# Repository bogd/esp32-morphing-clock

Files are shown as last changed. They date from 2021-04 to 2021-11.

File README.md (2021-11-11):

# esp32-morphing-clock
ESP32 HUB75 Matrix Morphing Clock

A clock based on a HUB75 RGB LED matrix, controlled by an ESP32.



So far, it does the following:
* Displays the current date, time, and day of the week
* Updates the time on startup and periodically, via NTP
* Displays the current outdoor temperature and humidity (received via MQTT - if you want to use this, you will need an MQTT server and a separate temperature sensor publishing to it!)
* Displays the current light levels, read via a TSL2591 I2C light sensor
* Displays the weather forecast for current day (including min/max temperatures), and for the next 4 days
* Can receive OTA updates, triggered via an MQTT message (of course, this also requires an MQTT server :) )

This is very much a work in progress, and it is far from being finished. Things that are planned for the future include:
* Use the current light levels to control the matrix brightness
* Display alerts on-screen (received via MQTT)
* Use the buzzer module to get the user's attention when an alert comes in

You can find the "components" for the project here:
* The full source code is [here](code/)  - requires PlatformIO!
* The schematics for the PCB used is [here](pcb/)
* The drawings for the lasercut plexiglass enclosure are [here](case/)

## Changelog

### Version 0.2
* Added MQTT SSL support (thanks to [Andreas](https://github.com/lefty01)). Disabled by default, since I do not use it when testing
* Implemented weather forecast - clock now displays min/max temperature for today, today's + next 4 days' forecast icons
* Decreased light sensor read interval (interval is now configurable from config.h)
* Added a watchdog timer to automatically reset the unit (sometimes the main thread seems to hang, possibly due to the light sensor read?)

## Thanks

This project would not have been possible without the work of many others, who have been gracious enough to open source their work. Some of the things that I have used when building this:
* The MQTT SSL code contributed by [Andreas](https://github.com/lefty01)
* The PxMatrix library from [2dom](https://github.com/2dom/PxMatrix). Even though this is NOT used in this project (I switched to the DMA library below, for performance reasons), it is the library that got me started on working with HUB75 matrices.
* The ESP32 DMA library for controlling the matrix, from [mrfaptastic](https://github.com/mrfaptastic/ESP32-HUB75-MatrixPanel-I2S-DMA)
* The morphing clock code from [HariFun](https://www.instructables.com/Morphing-Digital-Clock/) (modified to work with mrfaptastic's library instead of pxmatrix)
* The shield schematics from [hallard](https://github.com/hallard/WeMos-Matrix-Shield-DMA), which gave me the confidence to try building my own version of a shield PCB :)

And, of course, all the authors of the various open source libraries (there are already too many to mention :) ).

I also have to mention here [Brian Lough's work](https://www.tindie.com/products/brianlough/esp32-i2s-matrix-shield/) on a shield for the matrix. Even though he decided not to open source the board (he only sells the finished board on tindie), he has been extremely helpful during my initial work on the project. So if you are looking for a simple option for getting the full kit (shield and components, all in one package), take a look at [his tindie page](https://www.tindie.com/products/brianlough/esp32-matrix-shield-mini-32/) .

## License

The ESP32 HUB75 Matrix Morphing Clock is (c) [Bogdan Sass](https://github.com/bogd), licensed with GNU General Public License Version 3.0 (which means, if you use it in a product somewhere, you need to make the source and all your modifications available to the receiver of such product so that they have the freedom to adapt and improve).

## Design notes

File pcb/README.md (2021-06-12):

# ESP32 Morphing Clock Shield PCB

## Info

Features:
* 16-wire ribbon cable connection to the RGB matrix
* Mounting holes for securing the shield to the enclosure
* Options for both PTH and SMD (0805/SOD-323) parts for all parts
* Multiple JST-XH (2.54mm) connectors for I2C sensors and for GPIOs (use for push-buttons, for example)
* Exposed JTAG and PROG connectors, for use with debugging/programming via ESP32-Prog (although they are a bit too close together in v0.3 :) )

**WARNING!!** Do not use v0.1 of the boards! I have made several mistakes while designing them (reversed OE/LAT pins on the matrix connector, and put in a WAY too thin power supply trace). As a result, I was unable to get the ESP32 to even boot when connected to these boards.

v0.3 has been tested, and works reliably.

## Components

These are the components that you will need to populate the PCB:
* R1, R2 (I2C pull-up resistors) - 4k7 ohm, PTH or 0805 SMD
* C1,C2,C3 (decoupling capacitor(s)) - either 100uF PTH, or 2x47uF SMD
* D1 (protection diode, prevents the matrix from pulling too much power from your USB port) - any Schottky will work. For example: BAT85 (PTH), or 1N5819 (SOD-323)
* P1 - ribbon cable connector, 2x8 pin
* GND_T/5V_T - 2xScrew terminal blocks, 5.0mm
* power connection - 2.1/5.5mm PCB connector, or **7.62mm** screw terminal block
* I2C and GPIO connectors - JST-XH 2.54mm, 2 and 4-pin 

And, of course, you will need the ESP32 board - it has to be the D1 Mini version:
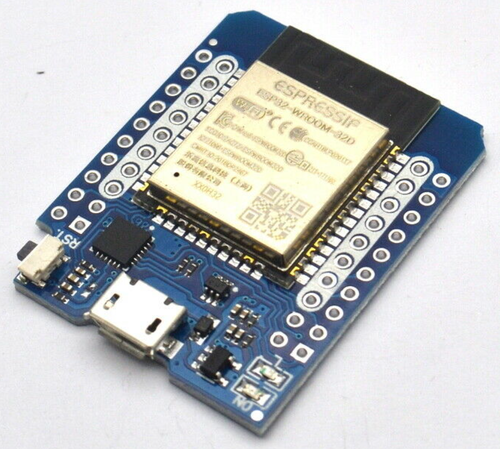
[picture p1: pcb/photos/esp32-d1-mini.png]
ESP32 D1 Mini


## Board 

Images of the completed board:
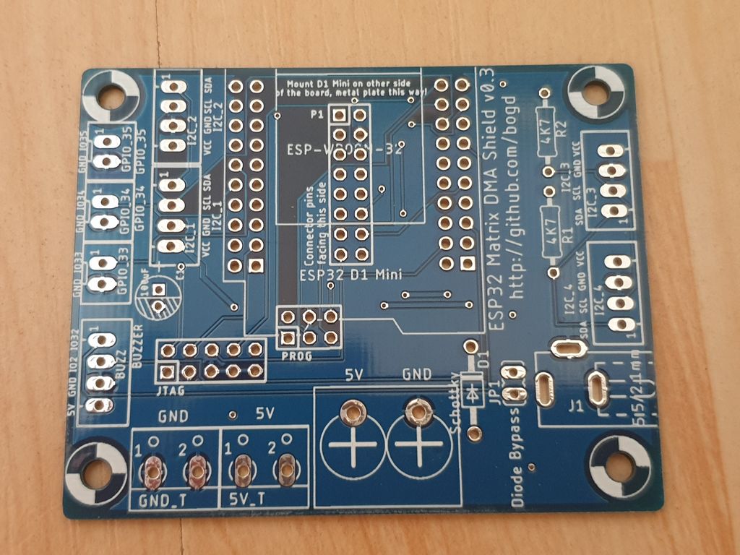
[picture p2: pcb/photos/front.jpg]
Front

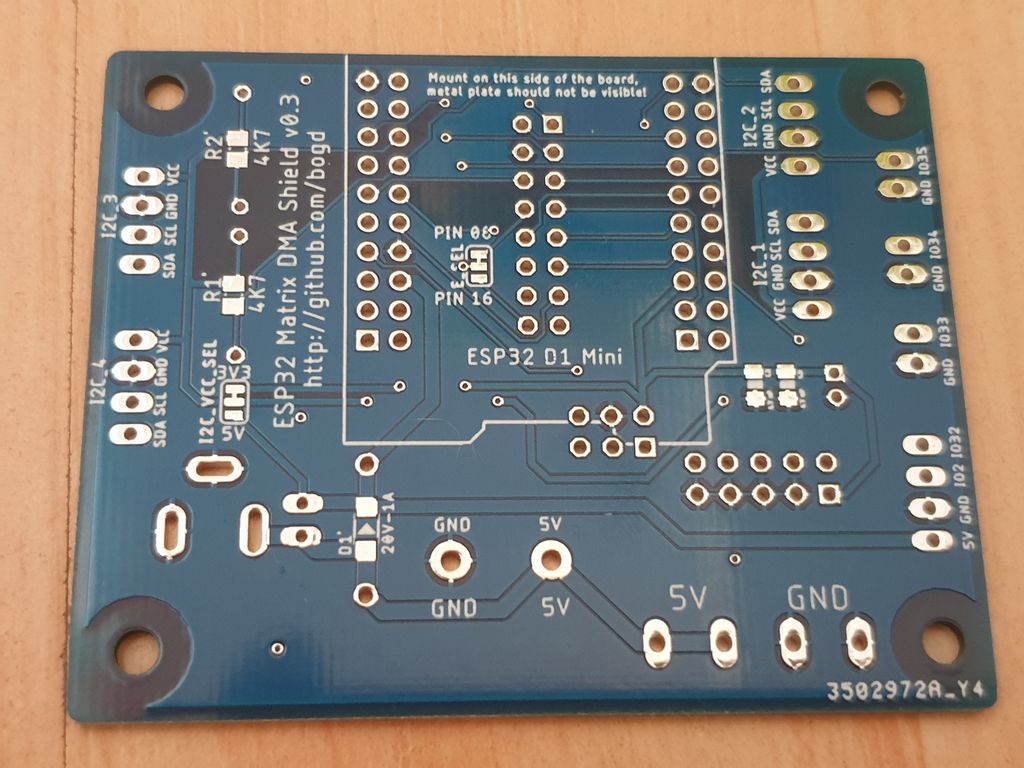
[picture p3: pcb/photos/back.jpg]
Back


The board with (a minimum of) components soldered on:
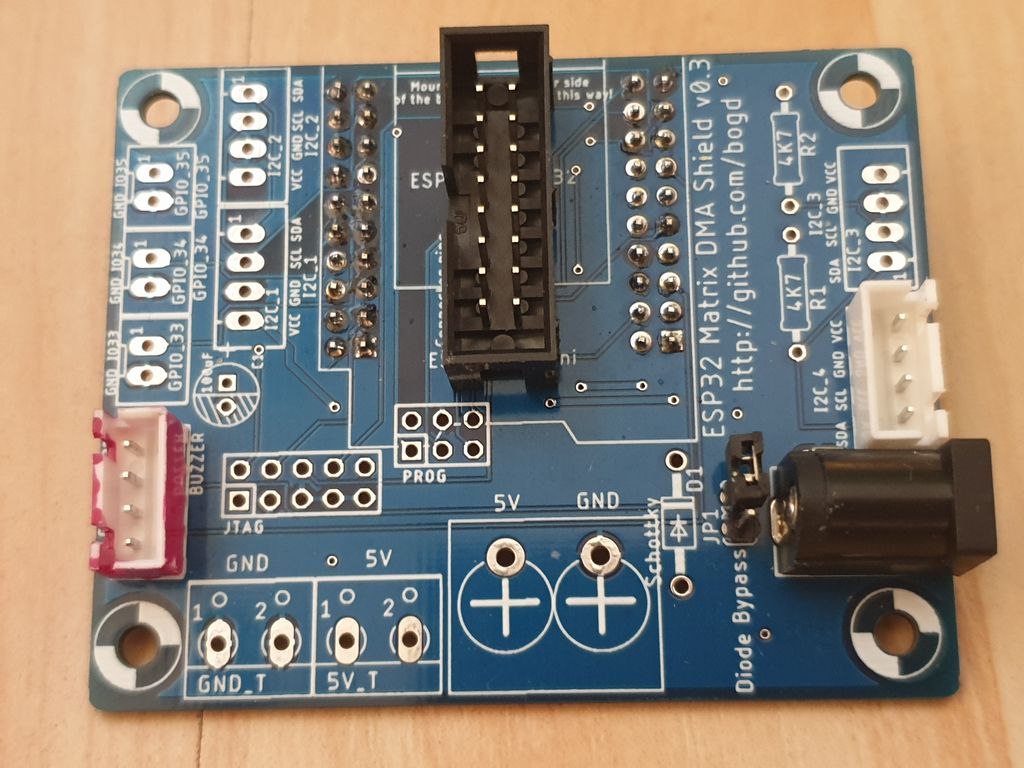
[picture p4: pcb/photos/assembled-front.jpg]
Assembled Front

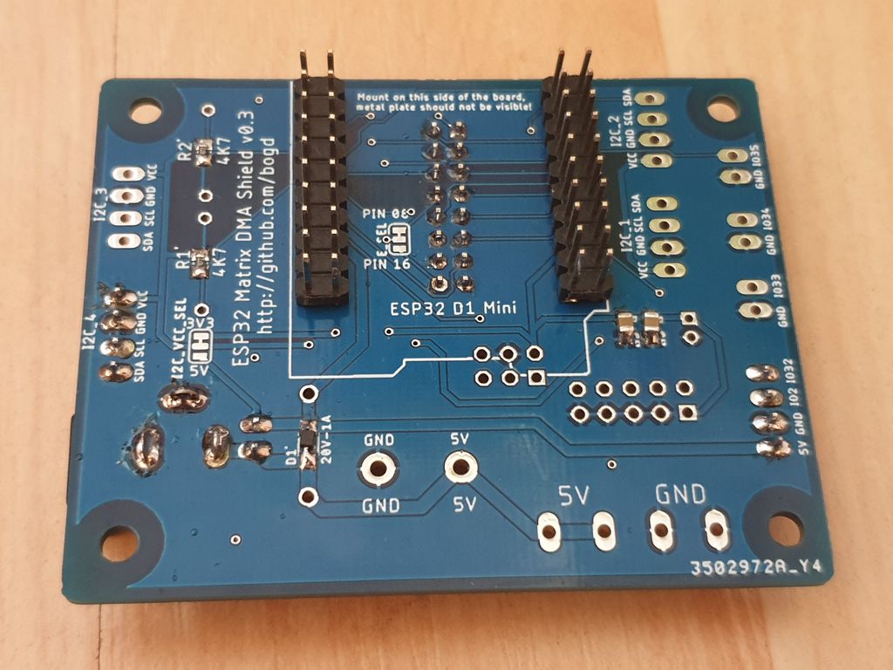
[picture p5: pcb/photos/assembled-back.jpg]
Assembled Back


Connected to the matrix and the ESP32 module:
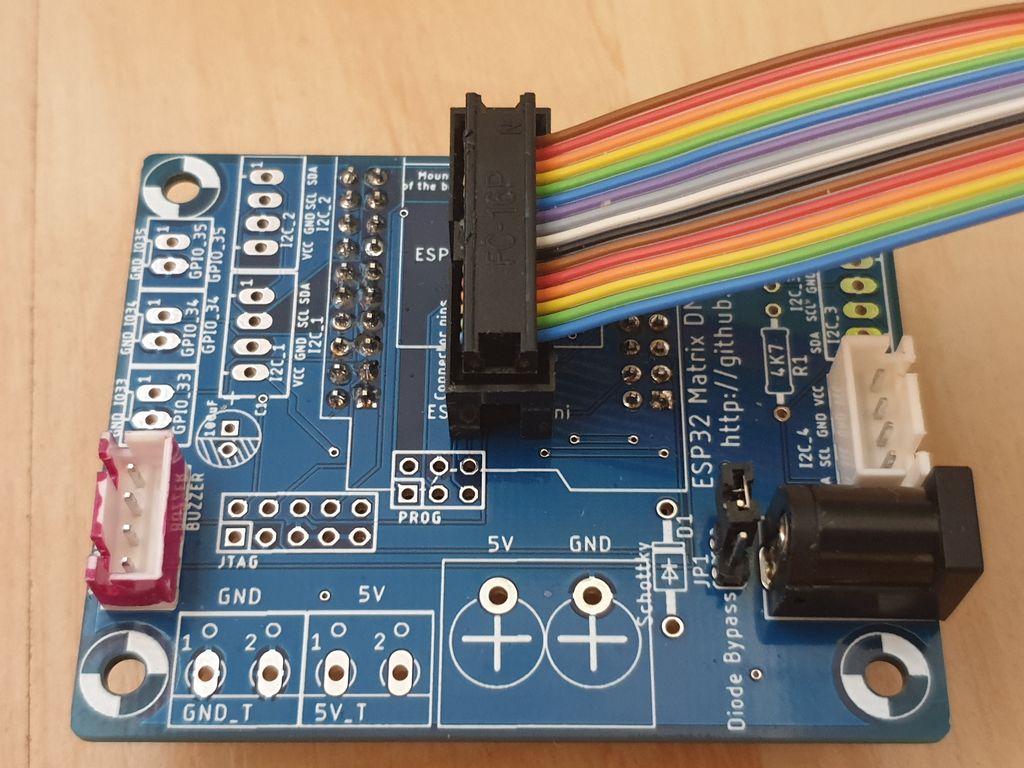
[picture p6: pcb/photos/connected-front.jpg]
Connected Front

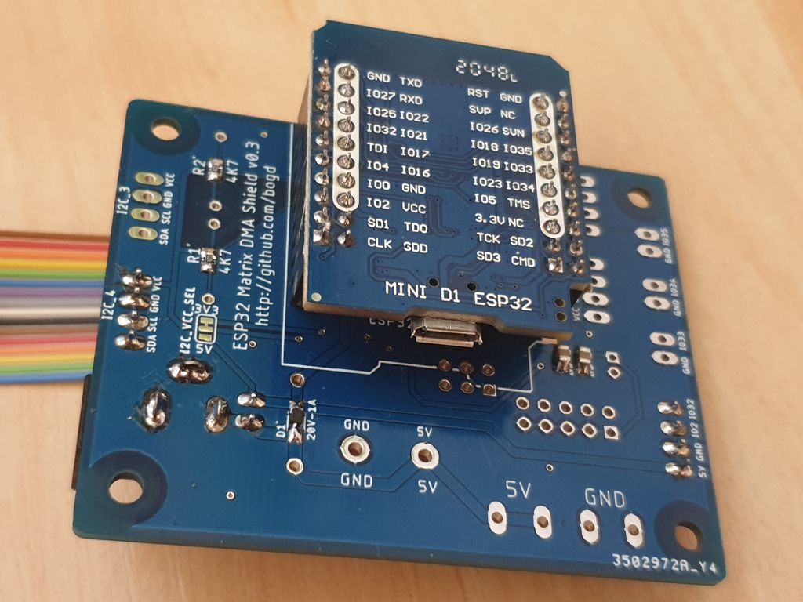
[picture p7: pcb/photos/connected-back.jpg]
Connected Back


## Schematic

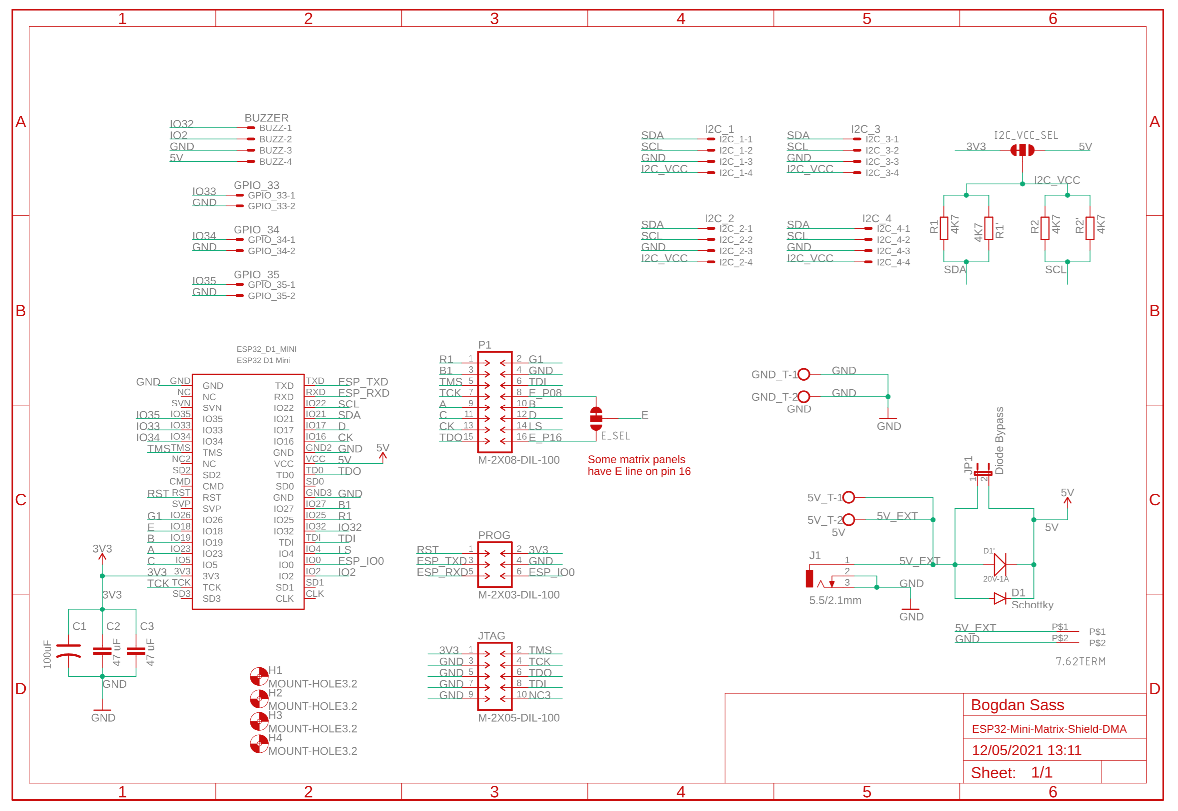
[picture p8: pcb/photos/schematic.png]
Schematic


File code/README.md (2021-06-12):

# ESP32 Morphing Clock Shield Code

## Info

This is the code for my morphing clock project. See [the main Readme file](../) for features that are already implemented or still work-in-progress.

## Before You Start

This requires PlatformIO (and if you are not already using it, do yourself a favor and learn - I have waited way too long before moving to PlatformIO, and I truly regret not doing that sooner! :) ).

You will need some external components in order for all the features to work:
* The temperature/humidity display requires an external MQTT server, and a sensor pushing the data to that MQTT server
* OTA updates require a web server for serving the firmware, and an MQTT server for triggering the updates

Also, you will need to create your own versions of the creds\_\*.h files. I cannot share my versions (for obvious reasons :) ), but I did create some creds\_\*.h.sample files to show you what the contents should look like.

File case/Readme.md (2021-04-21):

# ESP32 Morphing Clock Case

## Intro

This is a design for a case matching my model of RGB matrix.

You should be able to take this to your favorite laser cutting place, and ask them to cut it out of 3mm thick plexiglass (it has to be 3mm, otherwise you will need to adjust the size of the tabs!).

All the dimensions in the file are in mm, and the model has already been placed on a standard 450x600mm sheet of plexiglass.

As per my fab requirements, the red lines are for cutting, and the green lines are for line engraving. Everything else in the file is ignored.

**IMPORTANT!** The exact dimensions of the matrix (the plastic frame, and the mounting screw holes) may vary - even for the same product, from the same vendor! Whenever possible, ask your matrix vendor for the technical drawings of the particular model you bought, and use the dimensions from those drawings to adjust the design!!

## Features

* Holes for routing a 110V/230V power cable from the side
* Two power options - 5V via 5.5/2.1mm jack, or 110/230V with internally mounted 5V AC/DC power supply
* Holes on the back for mounting two types of 230V-to-5V AC/DC power supplies (optional)
* Cable holders for securely mounting the power cable to the side of the case (the small rectangular things with two screw holes each)
* Holes on the sides for panel-mount switches, push-buttons, and TSL2591 and TSL2561 light sensors
* Holes on the top for TSL2561/TSL2591 
* Holes on the back, top and bottom for mounting pot-type magnets for attaching it to metal supports
* Holes on the back for mounting a buzzer module
* Fits perfectly into an Ikea BOTKYRKA metal shelf (and since the shelf is made of metal, you can use the magnets to hold it securely)

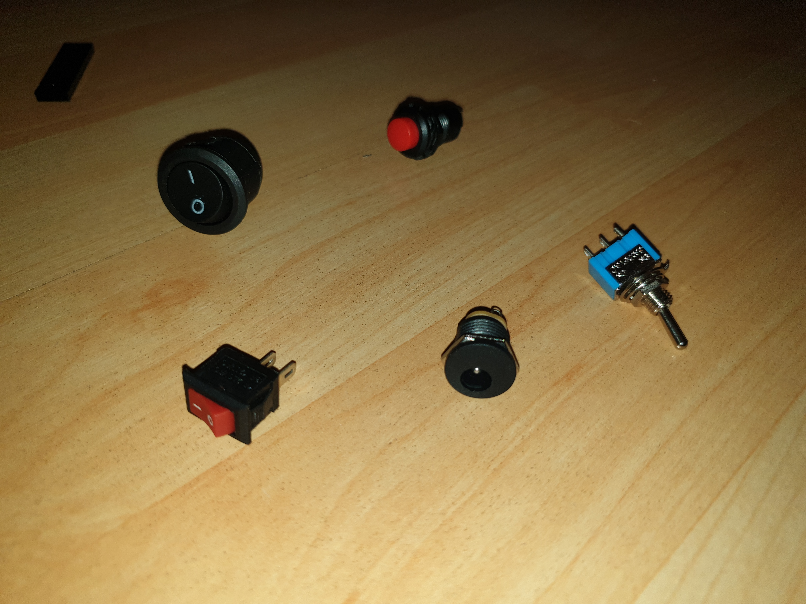
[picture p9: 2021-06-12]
case/photos/2021-04-21 19.43.02.jpg

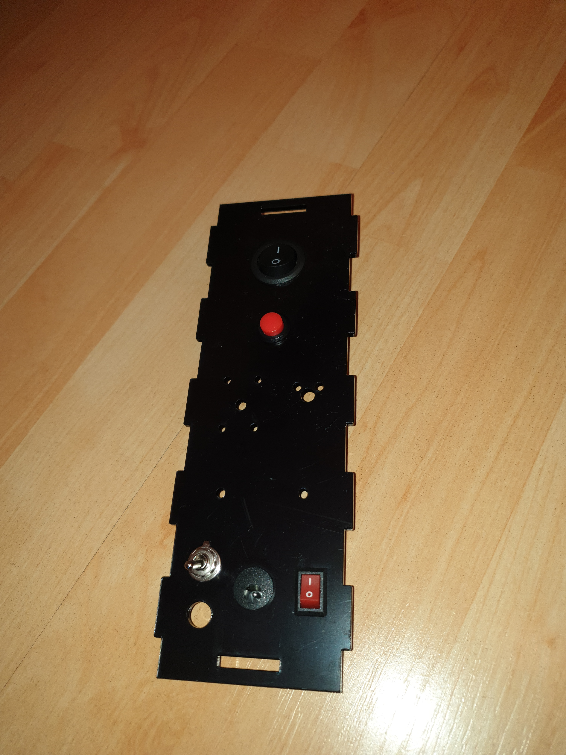
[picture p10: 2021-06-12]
case/photos/2021-04-21 19.39.49.jpg

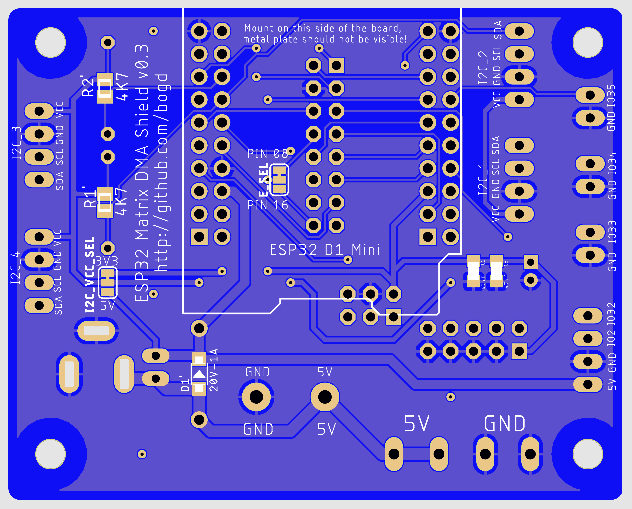
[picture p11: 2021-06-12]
pcb/photos/gerber-back.png

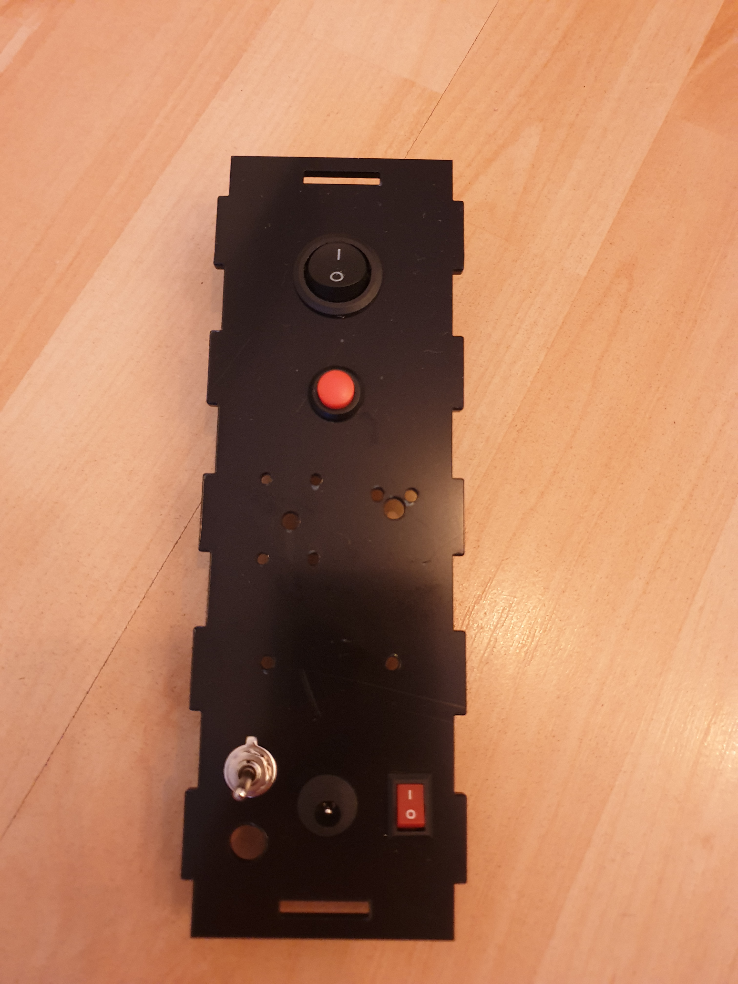
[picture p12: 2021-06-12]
case/photos/2021-04-21 19.39.38.jpg

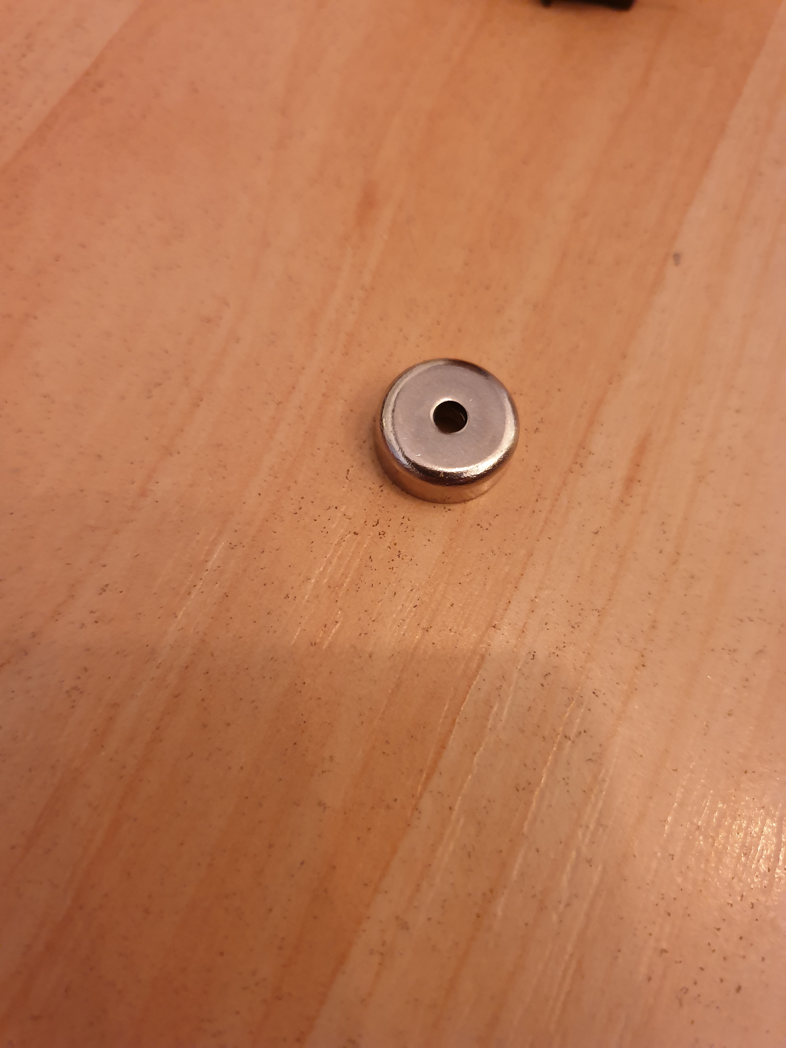
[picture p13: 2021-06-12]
case/photos/2021-04-21 19.44.03.jpg

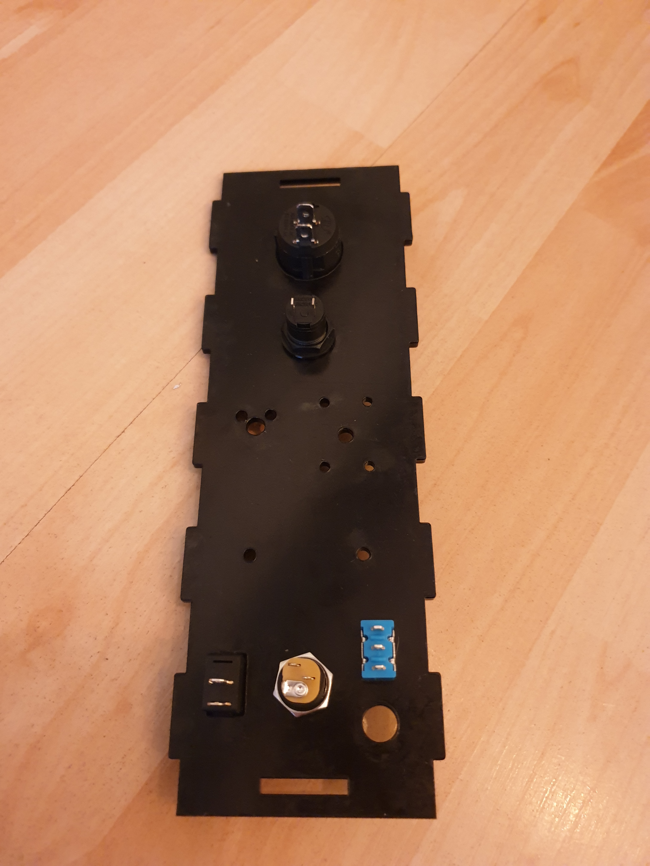
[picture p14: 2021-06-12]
case/photos/2021-04-21 19.39.59.jpg

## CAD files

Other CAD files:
case/lasercut.dwg

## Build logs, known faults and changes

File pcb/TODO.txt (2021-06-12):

## New in v0.2

* Added PTH option for the 5V protection diode (BAT85 or another Schottky will work)
* Moved ESP module to the edge of the board, to get some additional clearance between the antenna and the ground plane
* Added silkscreen documentation to both sides of the board
* Rounded all the corners of the board (I had missed one in v0.1 :) )

## New in v0.3

* Increased size of silkscreen instructions (they were almost unreadable in previous versions)
* Moved screw terminals closer to the edge of the board, to make connection easier
* Corrected reversed OE and LS on the HUB75E connector
* Increased width of 5V power trace for ESP32
* Exposed debugging pins to dedicated header
* Rotated 2.1/5.5mm power jack to make the board fit in the case with the jack connected
* Added JTAG/PROG connectors for ESP32-prog programming and debugging

## TODO in v0.4

* Increase spacing around JTAG/PROG to allow for shrouded connectors
* Change diode SMD footprint to make it easier to solder?

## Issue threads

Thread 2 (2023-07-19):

Scale to single 64x32?

jimmyeao, 2023-07-19:
Anyway this can scale to a single 64x32 Matrix? I changed the size in config.h, but everything is clipped or overwritten.
Great project by the way :)

jimmyeao, 2023-07-21:
[https://github.com/jimmyeao/esp32-morphing-clock](https://github.com/jimmyeao/esp32-morphing-clock)
Managed to shift a few things around to make it fir on a smaller display, sacrificed the 5 day forecast and MQTT Readings
Maybe it needs to have "Pages" on the lower half of the screen so it can flip between Date & Lo/Hi temp to Forecast and sensors
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

bogd, 2023-07-27:
My apologies, I didn't see the issue in time (I missed the notification).

As you have already figured out, getting everything to fit into a smaller matrix will require some resizing.

Quick hint - you can also resize the weather icons. I have enlarged them by a factor of two to make them more readable on the larger matrix - but you can just draw them at their original size by calling `drawBitmap` with `enlarged=false` (in `weather.cpp`, `drawWeatherIcon`)

Closed 2023-07-27.

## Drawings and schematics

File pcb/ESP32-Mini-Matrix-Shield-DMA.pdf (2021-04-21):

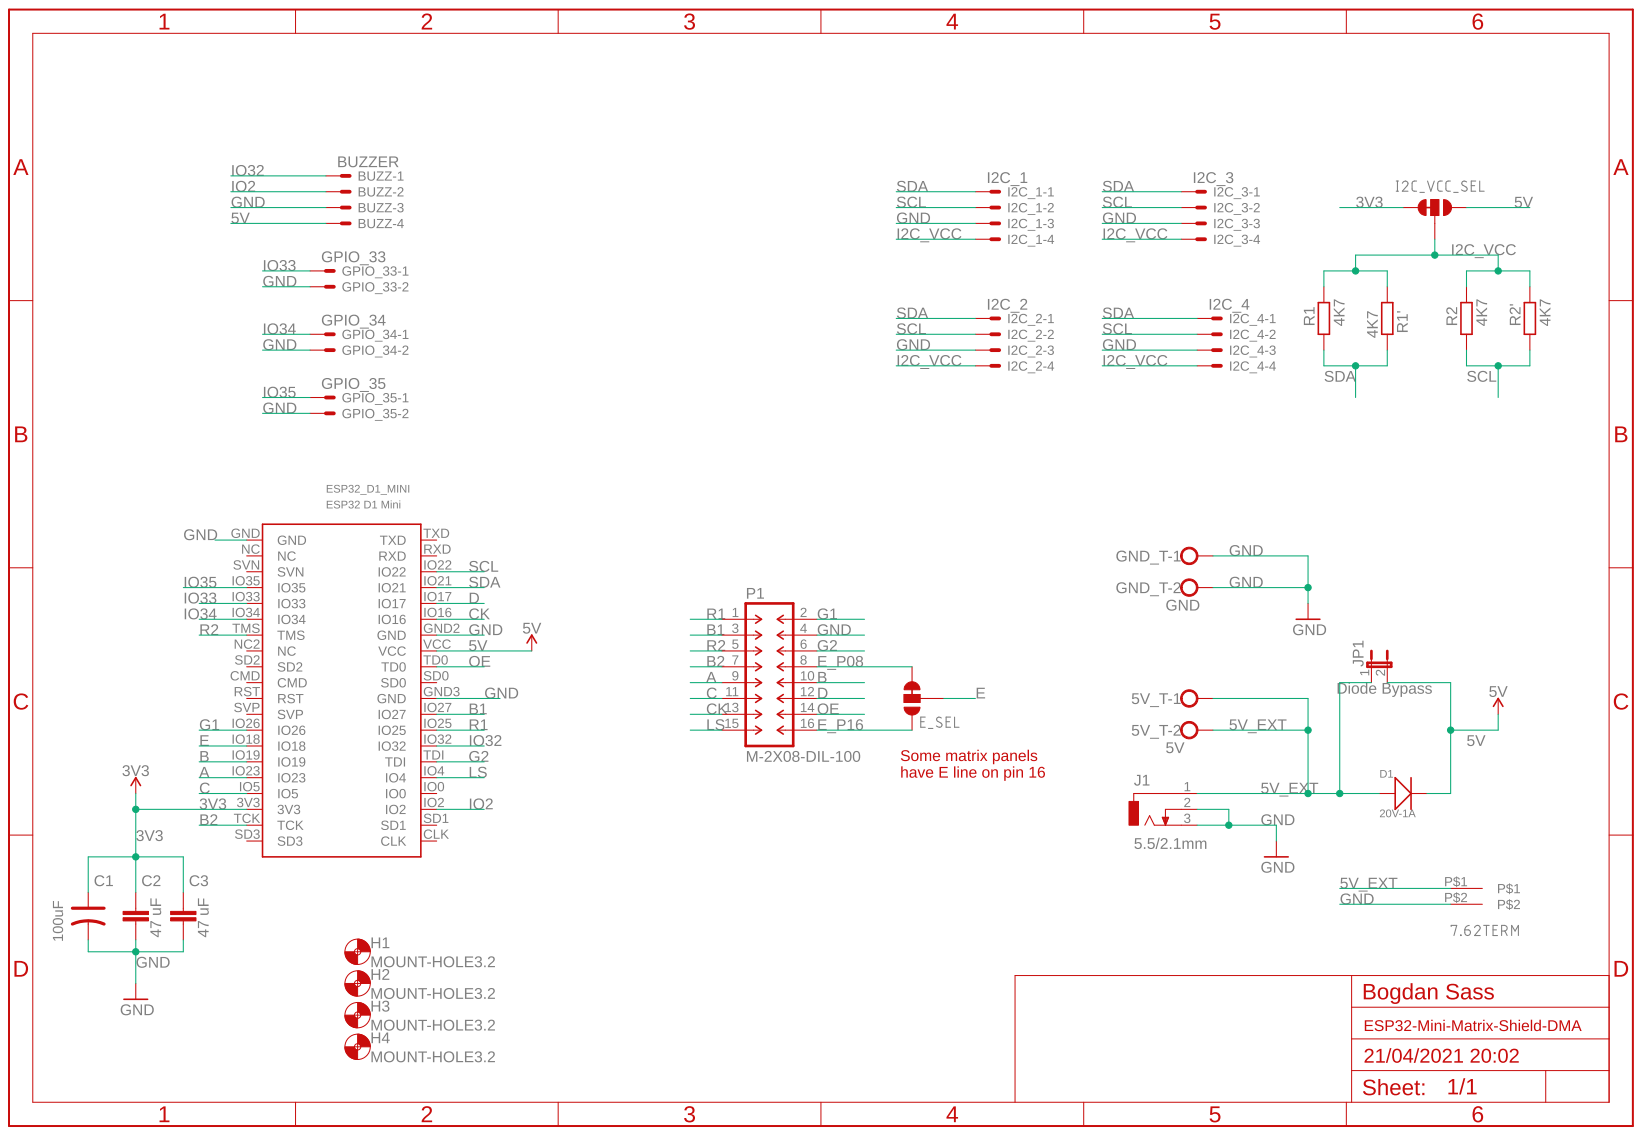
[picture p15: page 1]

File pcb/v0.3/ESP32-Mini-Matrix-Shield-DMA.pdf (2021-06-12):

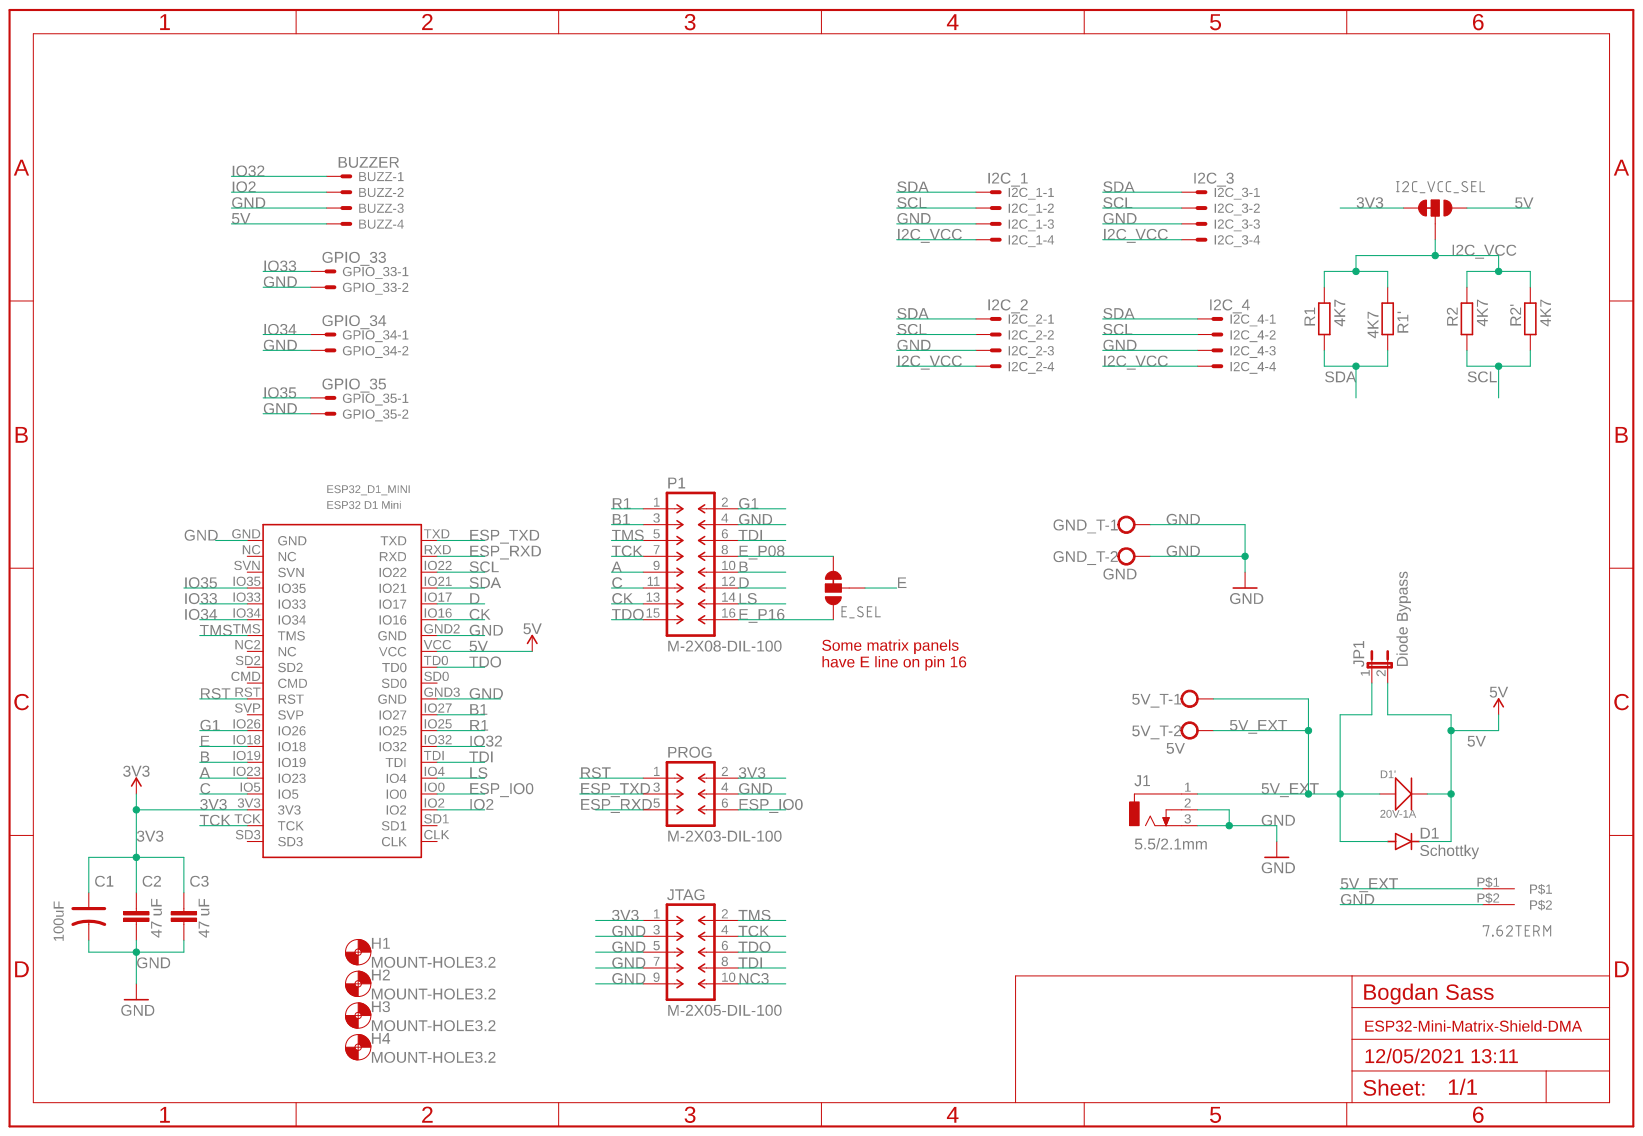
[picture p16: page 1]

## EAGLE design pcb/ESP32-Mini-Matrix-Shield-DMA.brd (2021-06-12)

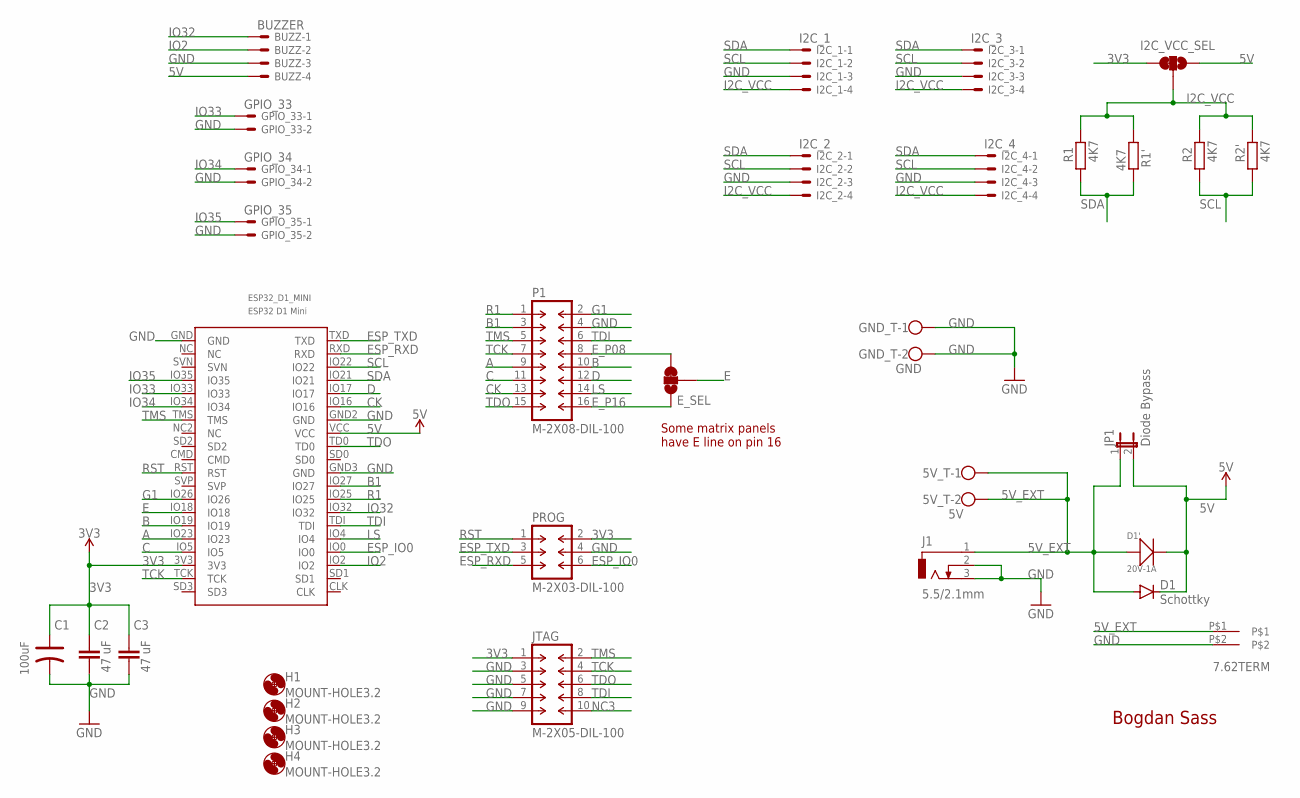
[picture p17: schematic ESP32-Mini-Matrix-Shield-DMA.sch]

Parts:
5V_T: 5V; W237-102
BUZZ: BUZZER; JST-XH-04-PACKAGE-LONG-PAD
C1: 100uF; PC-D5.3MM
C2, C3: 47 uF; 0805-CAP-LARGEPADS
D1: Schottky; DO41-10
D1': 20V-1A; SOD-123
ESP32_D1_MINI: ESP32 D1 Mini; MH-ET_ESP32_D1_MINI
E_SEL: JUMPER-SMT_3_1-NC_TRACE_SILK; SMT-JUMPER_3_1-NC_TRACE_SILK
GND_T: GND; W237-102
GPIO_33: GPIO_33; JST-XH-02-PACKAGE-LONG-PAD
GPIO_34: GPIO_34; JST-XH-02-PACKAGE-LONG-PAD
GPIO_35: GPIO_35; JST-XH-02-PACKAGE-LONG-PAD
H1, H2, H3, H4: MOUNT-HOLE3.2; 3,2
I2C_1: I2C_1; JST-XH-04-PACKAGE-LONG-PAD
I2C_2: I2C_2; JST-XH-04-PACKAGE-LONG-PAD
I2C_3: I2C_3; JST-XH-04-PACKAGE-LONG-PAD
I2C_4: I2C_4; JST-XH-04-PACKAGE-LONG-PAD
I2C_VCC_SEL: JUMPER-SMT_3_1-NC_TRACE_SILK; SMT-JUMPER_3_1-NC_TRACE_SILK
J1: 5.5/2.1mm; DCJ0303
JP1: Diode Bypass; JP1
JTAG: M-2X05-DIL-100; DIL-100-2X05
P1: M-2X08-DIL-100; DIL-100-2X08
PROG: M-2X03-DIL-100; DIL-100-2X03
R1, R2: 4K7; 0207/10
R1', R2': 4K7; M0805
ST_01: ST_01; CON-TERM-7.62

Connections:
3V3: C1.+, C2.1, C3.1, ESP32_D1_MINI.3V3, I2C_VCC_SEL.3, JTAG.1, PROG.2
5V: BUZZ.4, D1.C, D1'.-, ESP32_D1_MINI.VCC, I2C_VCC_SEL.1, JP1.2
5V_EXT: 5V_T.1, 5V_T.2, D1.A, D1'.+, J1.1, JP1.1, ST_01.P$1
A: ESP32_D1_MINI.IO23, P1.9
B: ESP32_D1_MINI.IO19, P1.10
B1: ESP32_D1_MINI.IO27, P1.3
C: ESP32_D1_MINI.IO5, P1.11
CK: ESP32_D1_MINI.IO16, P1.13
D: ESP32_D1_MINI.IO17, P1.12
E: ESP32_D1_MINI.IO18, E_SEL.2
ESP_IO0: ESP32_D1_MINI.IO0, PROG.6
ESP_RXD: ESP32_D1_MINI.RXD, PROG.5
ESP_TXD: ESP32_D1_MINI.TXD, PROG.3
E_P08: E_SEL.3, P1.8
E_P16: E_SEL.1, P1.16
G1: ESP32_D1_MINI.IO26, P1.2
GND: BUZZ.3, C1.-, C2.2, C3.2, ESP32_D1_MINI.GND, ESP32_D1_MINI.GND2 (GND), ESP32_D1_MINI.GND3 (GND), GND_T.1, GND_T.2, GPIO_33.2, GPIO_34.2, GPIO_35.2, I2C_1.3, I2C_2.3, I2C_3.3, I2C_4.3, J1.2, J1.3, JTAG.3, JTAG.5, JTAG.7, JTAG.9, P1.4, PROG.4, ST_01.P$2
I2C_VCC: I2C_1.4, I2C_2.4, I2C_3.4, I2C_4.4, I2C_VCC_SEL.2, R1.2, R1'.1, R2.2, R2'.2
IO2: BUZZ.2, ESP32_D1_MINI.IO2
IO32: BUZZ.1, ESP32_D1_MINI.IO32
IO33: ESP32_D1_MINI.IO33, GPIO_33.1
IO34: ESP32_D1_MINI.IO34, GPIO_34.1
IO35: ESP32_D1_MINI.IO35, GPIO_35.1
LS: ESP32_D1_MINI.IO4, P1.14
NC3: JTAG.10
R1: ESP32_D1_MINI.IO25, P1.1
RST: ESP32_D1_MINI.RST, PROG.1
SCL: ESP32_D1_MINI.IO22, I2C_1.2, I2C_2.2, I2C_3.2, I2C_4.2, R2.1, R2'.1
SDA: ESP32_D1_MINI.IO21, I2C_1.1, I2C_2.1, I2C_3.1, I2C_4.1, R1.1, R1'.2
TCK: ESP32_D1_MINI.TCK, JTAG.4, P1.7
TDI: ESP32_D1_MINI.TDI, JTAG.8, P1.6
TDO: ESP32_D1_MINI.TD0, JTAG.6, P1.15
TMS: ESP32_D1_MINI.TMS, JTAG.2, P1.5

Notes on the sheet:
Bogdan Sass
Some matrix panels have E line on pin 16

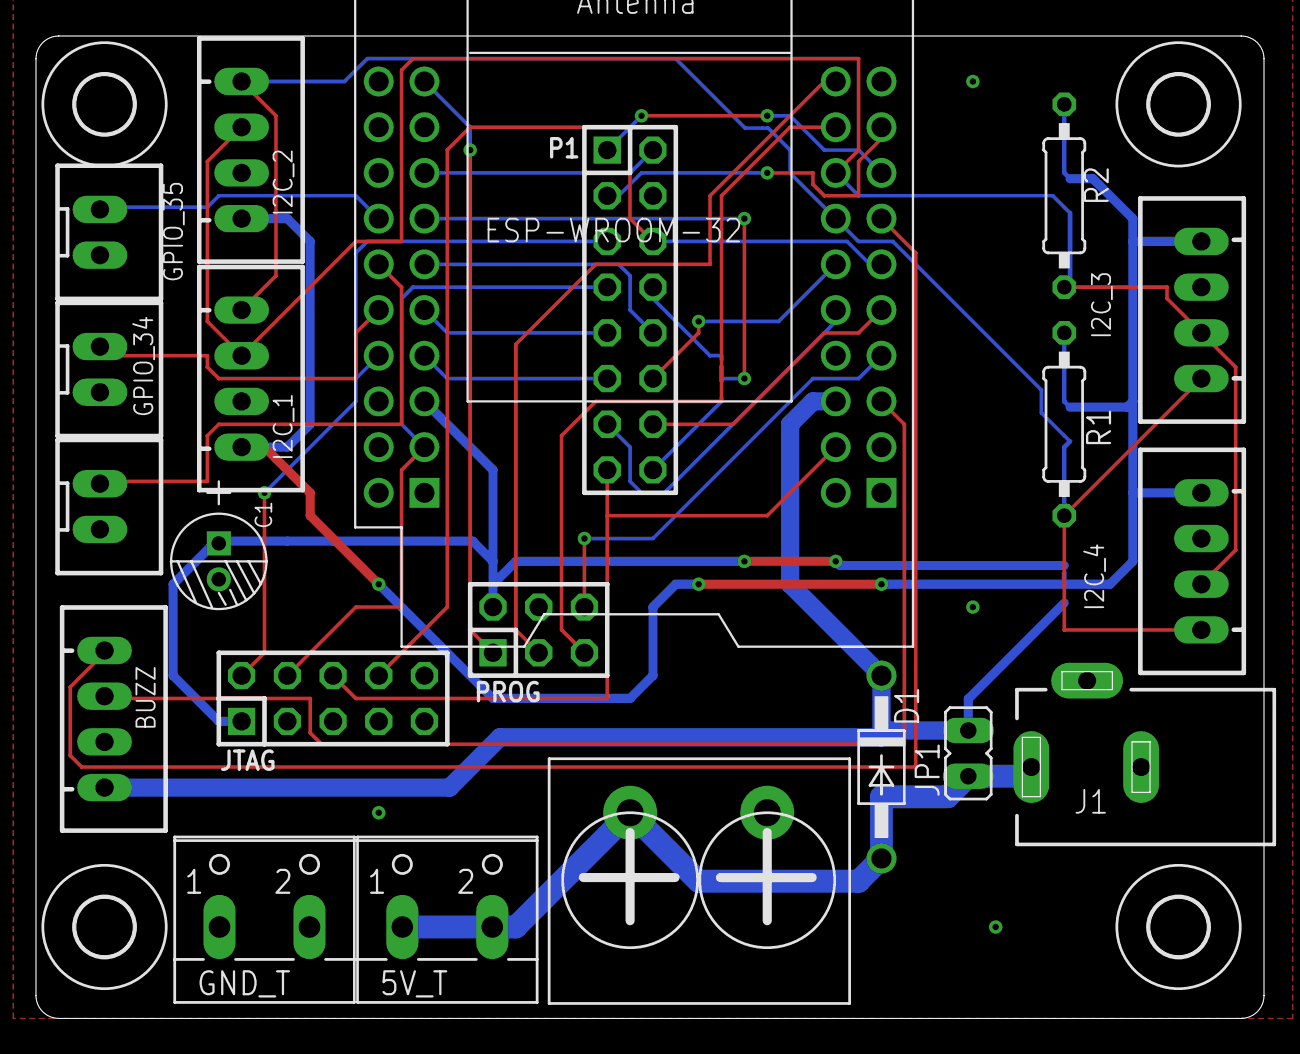
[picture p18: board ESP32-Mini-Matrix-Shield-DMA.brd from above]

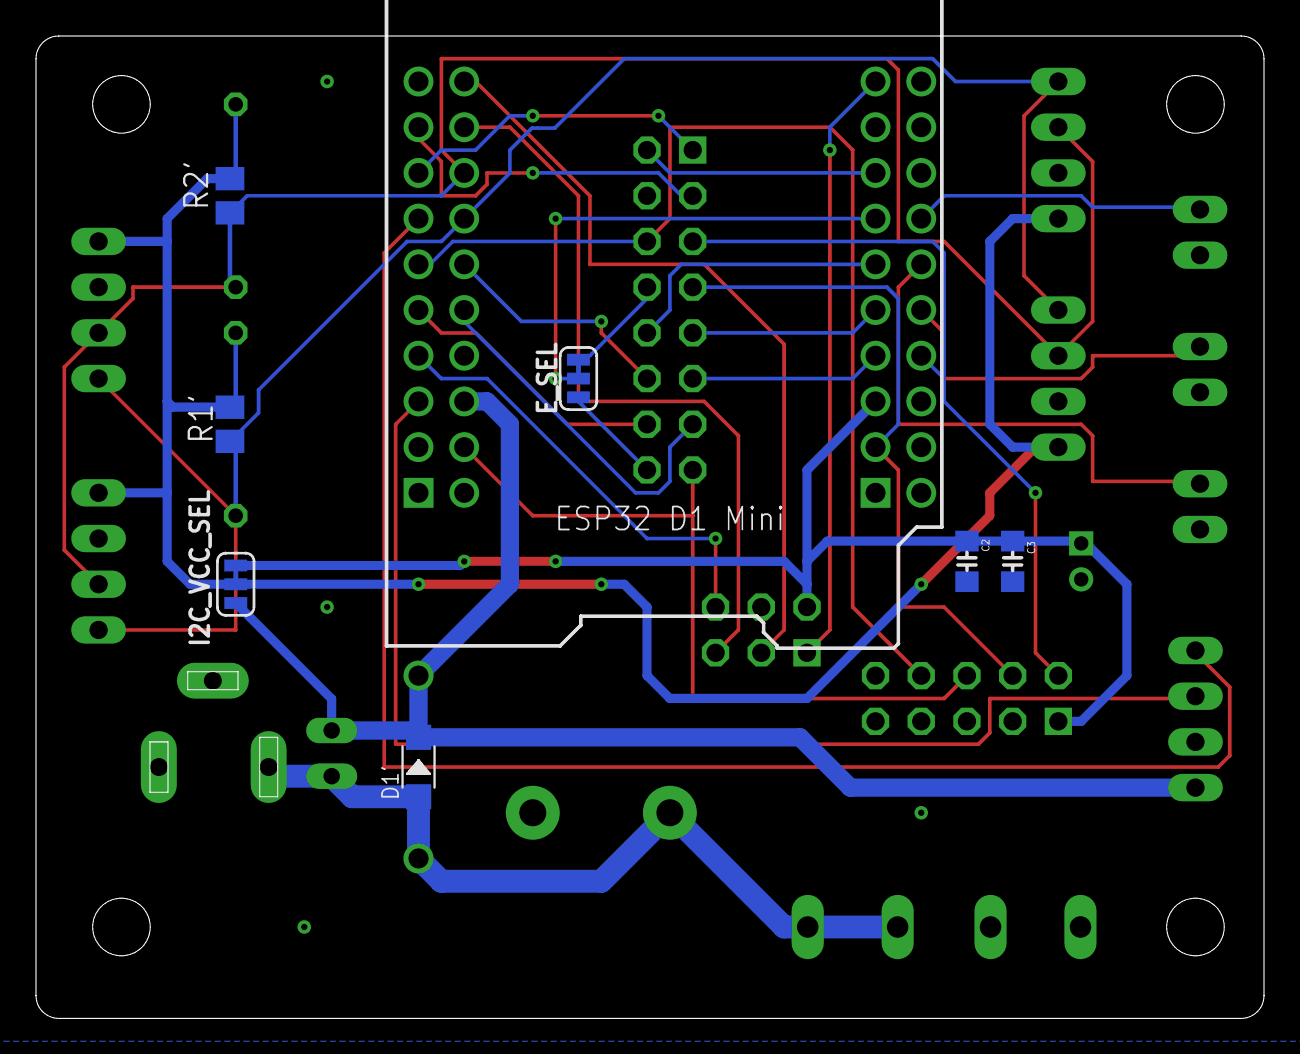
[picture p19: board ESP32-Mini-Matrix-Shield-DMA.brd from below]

Board: 2 copper layers, 68.2 x 54.6 mm, 32 parts (7 on the bottom side), 32 nets.

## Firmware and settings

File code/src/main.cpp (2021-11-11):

/*
ESP32 Matrix Clock - Copyright (C) 2021 Bogdan Sass

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
You should have received a copy of the GNU General Public License
along with this program.  If not, see <https://www.gnu.org/licenses/>.
*/

#include <Ticker.h>
#include <esp_task_wdt.h>

#include "main.h"
#include "common.h"
#include "rgb_display.h"
#include "mqtt.h"
#include "creds_mqtt.h"
#include "clock.h"
#include "weather.h"
#include "buzzer.h"

Ticker displayTicker;
unsigned long prevEpoch;
unsigned long lastNTPUpdate;
unsigned long lastWeatherUpdate;

//Just a blinking heart to show the main thread is still alive...
bool blinkOn;

void setup(){
  display_init();

  Serial.begin(115200);
  delay(10);

  pinMode(BUTTON1_PIN, INPUT_PULLUP);

  logStatusMessage("Buzzer setup");
  buzzer_init();
  buzzer_tone(500, 300);
  displayTest(300);
  
  logStatusMessage("Connecting to WiFi...");
  Serial.print("Connecting to ");
  Serial.println(WIFI_SSID);
  WiFi.begin(WIFI_SSID, WIFI_PASSWORD);
  while (WiFi.status() != WL_CONNECTED) {
    delay(500);
    Serial.print(".");
  }
  Serial.println("");
  Serial.println("WiFi connected.");
  logStatusMessage("WiFi connected!");

  logStatusMessage("NTP time...");
  configTime(TIMEZONE_DELTA_SEC, TIMEZONE_DST_SEC, "ro.pool.ntp.org");
  lastNTPUpdate = millis();
  logStatusMessage("NTP done!");

  logStatusMessage("Getting weather...");
  getAccuWeatherData();
  lastWeatherUpdate = millis();
  logStatusMessage("Weather recvd!");

  logStatusMessage("MQTT connect...");

  #ifdef MQTT_USE_SSL
  wifiClient.setCACert(server_crt_str);       
  wifiClient.setCertificate(client_crt_str);  
  wifiClient.setPrivateKey(client_key_str);   
  #endif

  client.setServer( MQTT_SERVER, MQTT_PORT );
  client.setCallback(mqtt_callback);
  reconnect();
  lastStatusSend = 0;
  logStatusMessage("MQTT done!");

  logStatusMessage("Initialize TSL...");
  tslConfigureSensor();
  logStatusMessage("TSL done!");

  logStatusMessage("Setting up watchdog...");
  esp_task_wdt_init(WDT_TIMEOUT, true);
  esp_task_wdt_add(NULL);
  logStatusMessage("Woof!");

  //logStatusMessage(WiFi.localIP().toString());
  drawTestBitmap();
  displayWeatherData();
  
  displayTicker.attach_ms(30, displayUpdater);
  
  buzzer_tone(1000, 300);
}

uint8_t wheelval = 0;
void loop() {
  if (WiFi.status() != WL_CONNECTED) {
    logStatusMessage("WiFi lost!");
    WiFi.reconnect();
  }

  if ( !client.connected() ) {
    logStatusMessage("MQTT lost");
    reconnect();
  }
  client.loop();

  // Periodically refresh NTP time
  if (millis() - lastNTPUpdate > 1000*NTP_REFRESH_INTERVAL_SEC) {
    logStatusMessage("NTP Refresh");
    configTime(TIMEZONE_DELTA_SEC, TIMEZONE_DST_SEC, "ro.pool.ntp.org");
    lastNTPUpdate = millis();
  }

  // Periodically refresh weather forecast
  if (millis() - lastWeatherUpdate > 1000 * WEATHER_REFRESH_INTERVAL_SEC) {
    logStatusMessage("Weather refresh");
    getAccuWeatherData();
    displayWeatherData();
    lastWeatherUpdate = millis();
  }

  if (digitalRead(BUTTON1_PIN) == LOW) {
    logStatusMessage("Yess... push it again!!");
  }

  //Do we need to clear the status message from the screen?
  if (logMessageActive) {
    if (millis() > messageDisplayMillis + LOG_MESSAGE_PERSISTENCE_MSEC) {
      clearStatusMessage();
      drawTestBitmap();
    }
  }

  // Do we have new sensor data?
  if (newSensorData) {
    //logStatusMessage("Sensor data in");
    displaySensorData();
    displayTodaysWeather();
  }

  // Is the sensor data too old?
  if (millis() - lastSensorRead > 1000*SENSOR_DEAD_INTERVAL_SEC) {
    sensorDead = true;
    displaySensorData();
    displayTodaysWeather();
  }

  heartBeat = !heartBeat;
  drawHeartBeat();
  if (millis() - lastLightRead > 1000*LIGHT_READ_INTERVAL_SEC) {
    lightUpdate();
    //displayTodaysWeather();
  } 

  //Reset the watchdog timer as long as the main task is running
  esp_task_wdt_reset();
  delay(500);
}

void displayUpdater() {
  if(!getLocalTime(&timeinfo)){
    logStatusMessage("Failed to get time!");
    return;
  }

  unsigned long epoch = mktime(&timeinfo);
  if (epoch != prevEpoch) {
    displayClock();
    prevEpoch = epoch;
  }
}

void lightUpdate() {
  float tslData = tslGetLux();
  lastLightRead = millis();
  if ((tslData >=0 ) && (tslData <= LIGHT_THRESHOLD)) {
    displayLightData(tslData);
  }
}

//TODO: http://www.rinkydinkelectronics.com/t_imageconverter565.php

//TODO - add heartbeat in loop(), reboot in interrupt if heartbeat lost (sometimes the system hangs during OTA request)
//https://iotassistant.io/esp32/enable-hardware-watchdog-timer-esp32-arduino-ide/

//TODO - get and print weather forecast every X interval (4h?)
//TODO - use light sensor data to set display brightness
//TODO - add option to turn off display via MQTT
//TODO - replace bitmap arrays with color565 values!
//TODO - add event-based wifi disconnect/reconnect - https://randomnerdtutorials.com/solved-reconnect-esp32-to-wifi/

//TODO - check asynchronously for buzzer stop
//TODO - move TSL read to async task

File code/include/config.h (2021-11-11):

#ifndef CONFIG_H
#define CONFIG_H

//#define MQTT_USE_SSL 1
//#define USE_ANDROID_AP 1

// How often we refresh the time from the NTP server
#define NTP_REFRESH_INTERVAL_SEC 3600

// Timezone difference from GMT, expressed in seconds
#define TIMEZONE_DELTA_SEC 7200
// DST delta to apply
#define TIMEZONE_DST_SEC 3600

// How long are informational messages kept on screen
#define LOG_MESSAGE_PERSISTENCE_MSEC 30000

// How long do we consider the sensor data valid before declaring the sensor dead
#define SENSOR_DEAD_INTERVAL_SEC 600

//Button pin
#define BUTTON1_PIN 32

//Buzzer pin
#define BUZZER_PIN 2
#define BUZZER_PWM_CHANNEL 0
#define BUZZER_PWM_RESOLUTION 8

// Screen positioning settings
// Panel size
#define PANEL_WIDTH 128
#define PANEL_HEIGHT 64

// Clock
#define CLOCK_X 3
#define CLOCK_Y 21
#define CLOCK_SEGMENT_HEIGHT 8
#define CLOCK_SEGMENT_WIDTH 8
#define CLOCK_SEGMENT_SPACING 5
#define CLOCK_WIDTH 6*(CLOCK_SEGMENT_WIDTH+CLOCK_SEGMENT_SPACING)+4
#define CLOCK_HEIGHT 2*CLOCK_SEGMENT_HEIGHT+3
//color565 == ((red & 0xF8) << 8) | ((green & 0xFC) << 3) | (blue >> 3)
#define CLOCK_DIGIT_COLOR  ((0x00 & 0xF8) << 8) | ((0xFF & 0xFC) << 3) | (0xFF >> 3)
//Delay in ms for clock animation - should be below 30ms for a segment size of 8
#define CLOCK_ANIMATION_DELAY_MSEC 20

// Day of week
#define DOW_X 90
#define DOW_Y 21
#define DOW_COLOR ((0x00 & 0xF8) << 8) | ((0x40 & 0xFC) << 3) | (0xFF >> 3)
// Date
#define DATE_X DOW_X
#define DATE_Y DOW_Y+11
#define DATE_COLOR DOW_COLOR
//Width and height are for both DATE and DOW
#define DATE_WIDTH 40
#define DATE_HEIGHT 18


// Weather sensor data
#define SENSOR_DATA_X 0
#define SENSOR_DATA_Y 0
#define SENSOR_DATA_WIDTH 128
#define SENSOR_DATA_HEIGHT 8
#define SENSOR_DATA_COLOR ((0x00 & 0xF8) << 8) | ((0x8F & 0xFC) << 3) | (0x00 >> 3)
#define SENSOR_ERROR_DATA_COLOR ((0xFF & 0xF8) << 8) | ((0x00 & 0xFC) << 3) | (0x00 >> 3)

// Light sensor data
#define LIGHT_DATA_X 0
#define LIGHT_DATA_Y 9
#define LIGHT_DATA_WIDTH 44
#define LIGHT_DATA_HEIGHT 8
#define LIGHT_DATA_COLOR ((0x00 & 0xF8) << 8) | ((0xFF & 0xFC) << 3) | (0x00 >> 3)
//Maximum lux value that will be accepted as valid (sometimes the sensor will return erroneous values)
#define LIGHT_THRESHOLD 9999
#define LIGHT_READ_INTERVAL_SEC 10

// Log messages at the bottom
#define LOG_MESSAGE_COLOR ((0xFF & 0xF8) << 8) | ((0x00 & 0xFC) << 3) | (0x00 >> 3)

#define BITMAP_X 0
#define BITMAP_Y 44

#define HEARTBEAT_X 120
#define HEARTBEAT_Y 21

// Watchdog settings
#define WDT_TIMEOUT 60   // If the WDT is not reset within X seconds, reboot the unit
        // Do NOT set this too low, or the WDT will prevent OTA updates from completing!!

// Weather - today, and 5-day forecast
#define WEATHER_TODAY_X 56
#define WEATHER_TODAY_Y 1

#define WEATHER_FORECAST_X 90
#define WEATHER_FORECAST_Y 44

//Temperature range for today
#define TEMPRANGE_X 0
#define TEMPRANGE_Y 44
#define TEMPRANGE_WIDTH 64
#define TEMPRANGE_HEIGHT 8
#define TEMPRANGE_COLOR ((0x00 & 0xF8) << 8) | ((0xFF & 0xFC) << 3) | (0xFF >> 3)

// How often to refresh weather forecast data
// (limited by API throttling)
#define WEATHER_REFRESH_INTERVAL_SEC 14400

#endif

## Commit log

2021-04-21 Added case designs
    [lasercut.dwg]
2021-04-21 Case designs readme
2021-04-21 Added PCBs
    [ESP32-Mini-Matrix-Shield-DMA.brd, ESP32-Mini-Matrix-Shield-DMA.sch]
2021-04-21 Added PCB Schematic
    [ESP32-Mini-Matrix-Shield-DMA.sch]
2021-04-21 Added Gerber photos
2021-06-12 Updated PCB to v0.3
    [ESP32-Mini-Matrix-Shield-DMA.brd, ESP32-Mini-Matrix-Shield-DMA.sch]
2021-06-12 Added PCB photos
2021-06-12 PCB Photos resize
2021-06-12 PCB readme update
2021-06-16 revert to 'official' LED MATRIX PANEL DMA Display lib
2021-11-09 Revert light sensor ticker
    [config.h, main.cpp]

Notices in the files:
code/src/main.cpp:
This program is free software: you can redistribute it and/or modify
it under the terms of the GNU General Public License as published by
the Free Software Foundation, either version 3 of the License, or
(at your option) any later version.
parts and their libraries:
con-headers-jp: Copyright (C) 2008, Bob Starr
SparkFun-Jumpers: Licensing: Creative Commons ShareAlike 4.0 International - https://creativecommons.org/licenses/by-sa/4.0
